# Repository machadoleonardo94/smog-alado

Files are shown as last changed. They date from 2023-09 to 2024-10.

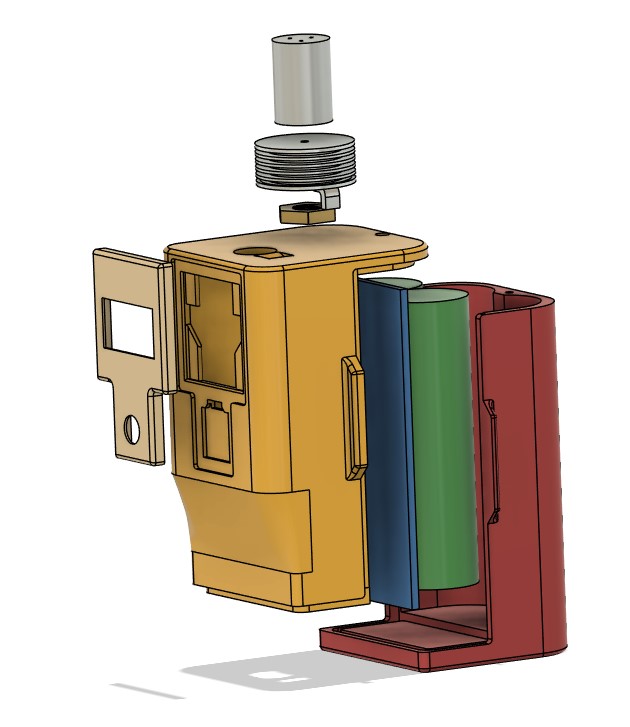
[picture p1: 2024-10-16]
3D files/Portable/Assembly.jpg

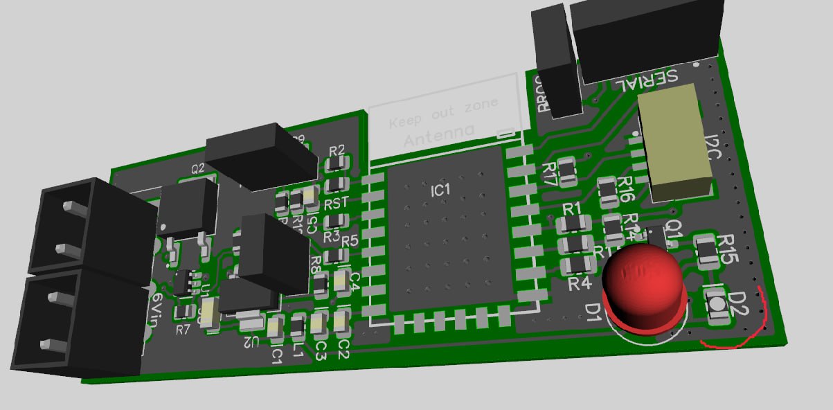
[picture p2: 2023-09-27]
board.jpg

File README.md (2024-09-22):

# smog-alado
Desktop and portable heating element controller.

## Tested uses: 
* Precise temperature control for coffee machines
* SMD soldering hotbed
* Aromatherapy diffusers

## Current hardware versions: ESP12F and ESP32-C3
* ESP12F board noes not support wakeup from deep sleep, but accepts 12V input. Aimed at desktop devices running on external power sources. It also uses the integrated ADC that requires calibration.
* ESP32-C3 board includes deepsleep, 16bit 4channel ADC (two thermistors, input voltage and current on load), USB type-C connector (charging and programming) and a WS2812B LED for debug and fancy lights.
* The 12F hardware version is considered done and more accessible, while the C3 version is a work in progress. Current C3 PCB version has wiring mistakes and should be avoided while the C3V2 is being built.
* Both versions can be wired on perfboard using NodeMCU modules and an external MOSFET or SSR if the challanger is bold.

## Mileage may vary, use at your own risk.

Portable version with 1S2P 18650 battery and 510 connector:



Portable version with 2S1P 21700, homemade heating element:



Current devkit:



## Main Features:
* PID heating to setpoint
* Single pushbutton control
* 0.96" OLED display
* OTA firmware upload
* Telnet debugging
* Auto power off

## Minimum required parts besides components BoM:
* 1x Power source
* 0.15mm NiCr wire
* Heat resistant cable  
* 1x RS232 USB to TTL module 
* 1x PCB
* 1x 100k NTC 3950 thermistor
* 1x 40N02 TO252 N-channel MOSFET or equivalent module
* 1x 12x12mm pushbutton (or whatever)
* 1x 0.96" OLED I2C display

## Recomended power sources (12F):
* 2S1P 21700 li-ion batteries with 2S BMS
* 2S lithium battery charger circuit
* 9V~12V 2A brick power supply

## Current issues (3C): 
* Missing GND connection on I2C connector;
* Button wrongly wired to 3V3. Cut the trace and connect directly to Vin;
* Gate driver does not hold MOSFET off, requires a bleeding resistor between gate and source MOSFET pins;
* 12 pin USB C connector is fucking terrible to solder correctly, so I've added an external header for serial programming and a backup 6 pin connector for charging;
* I had the dumb and forgot the antenna, so now I either solder an 1U footprint or deal with a lump on the 3D case.

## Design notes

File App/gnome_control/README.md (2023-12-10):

# gnome_control

A new Flutter project.

## Getting Started

This project is a starting point for a Flutter application.

A few resources to get you started if this is your first Flutter project:

- [Lab: Write your first Flutter app](https://docs.flutter.dev/get-started/codelab)
- [Cookbook: Useful Flutter samples](https://docs.flutter.dev/cookbook)

For help getting started with Flutter development, view the
[online documentation](https://docs.flutter.dev/), which offers tutorials,
samples, guidance on mobile development, and a full API reference.

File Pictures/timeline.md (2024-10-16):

## Project timeline 

### Gnome

October 2019. First device, running on 3D printer motherboard and firmware (Ramps 1.3 and Marlin 1.X).

### Gnome on the Cloud (IoD)



First prototype on dedicated hardware and firmware, with hookah hose outputs (up to 4).

### The Prism

Heating element fixed on high temperature silicone, replaceable with GX16-4 connector.

### Portable gnome

Running 3S batteries, able to run about 3 bowls before charging.

### First handheld device

Printed on glow in the dark filament.

### Current development version



With 2 21700 batteries, running on an ESP32-C3, focused on assembly ease.

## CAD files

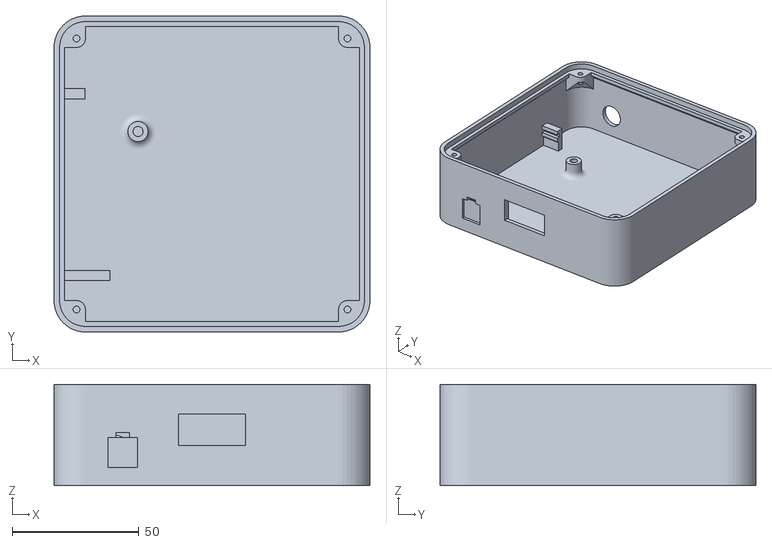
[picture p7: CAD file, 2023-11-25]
3D files/Desktop/Main body_120mm.stl
124.8 x 124.8 x 40.0

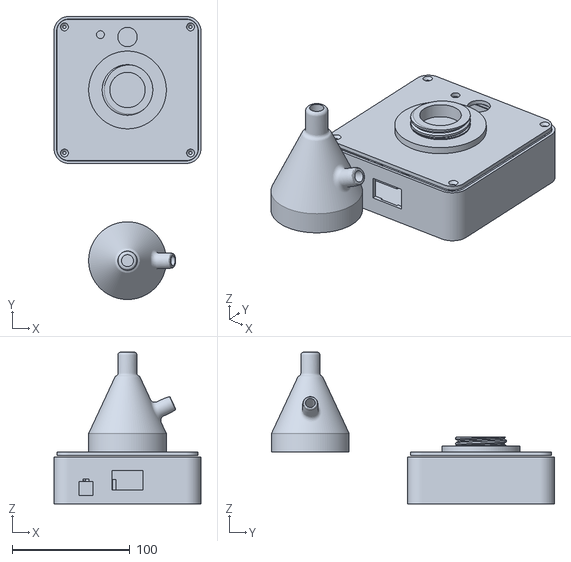
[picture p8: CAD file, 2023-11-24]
3D files/Desktop/Gnome_full.stl
124.8 x 240.4 x 129.0

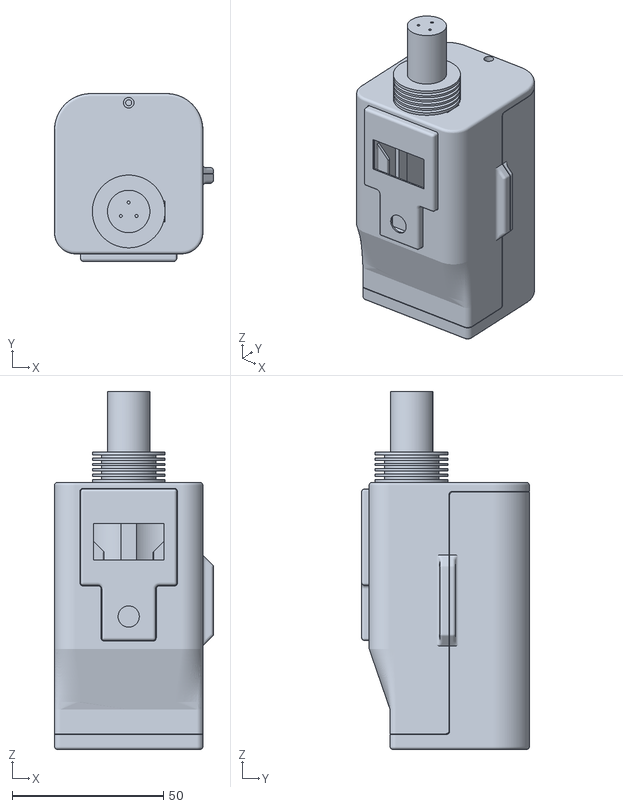
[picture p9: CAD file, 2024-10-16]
3D files/Portable/GnomeC3-V1 v23.stl
52.5 x 55.4 x 118.2

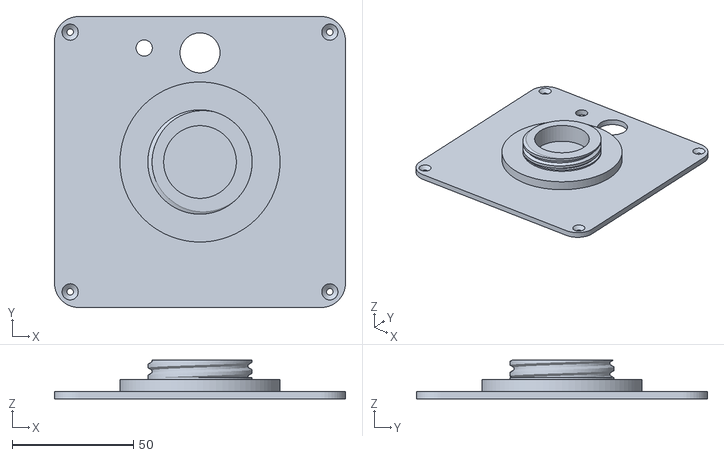
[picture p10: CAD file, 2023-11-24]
3D files/Desktop/Lid.stl
120.0 x 120.0 x 16.0

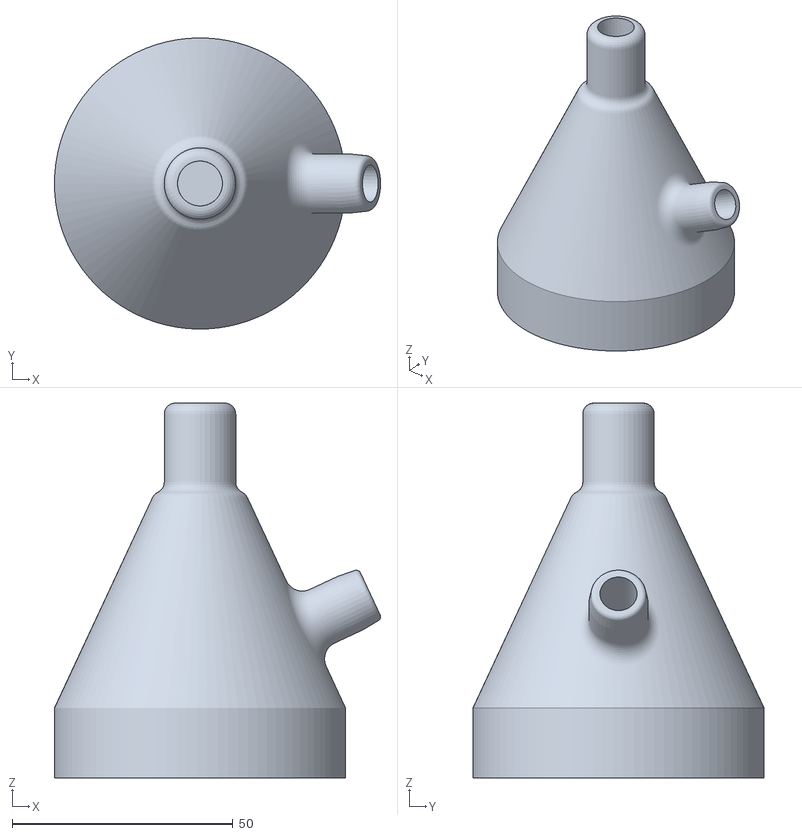
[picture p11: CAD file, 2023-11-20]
3D files/Desktop/Bowl_base_10mm.stl
73.9 x 66.0 x 85.0

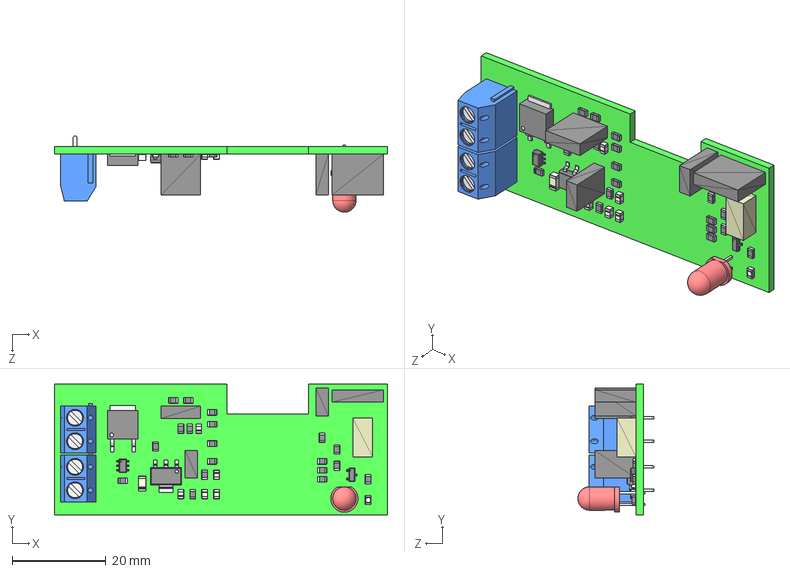
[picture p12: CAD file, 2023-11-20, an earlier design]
Board files/gnome_V3/3D_step.step
71.1 x 27.9 x 16.3 mm
Board_3D_step
DG306-5.0-02P-12-00AH x 2
CAPP_0805_M x 5
293D104X0035A2TE3
LED-5mm_Round_Red
LED_0805(2012_Metric)_M_Red
RES_0805_M x 19
2N7002,215
FDD86250-F085
FD2024S
AMS1117-3.3V
BM04B-GHS-TBT(LF)(SN)
PPTC021LFBN-RC x 2
PPTC041LFBN-RC
PPTC031LFBN-RC

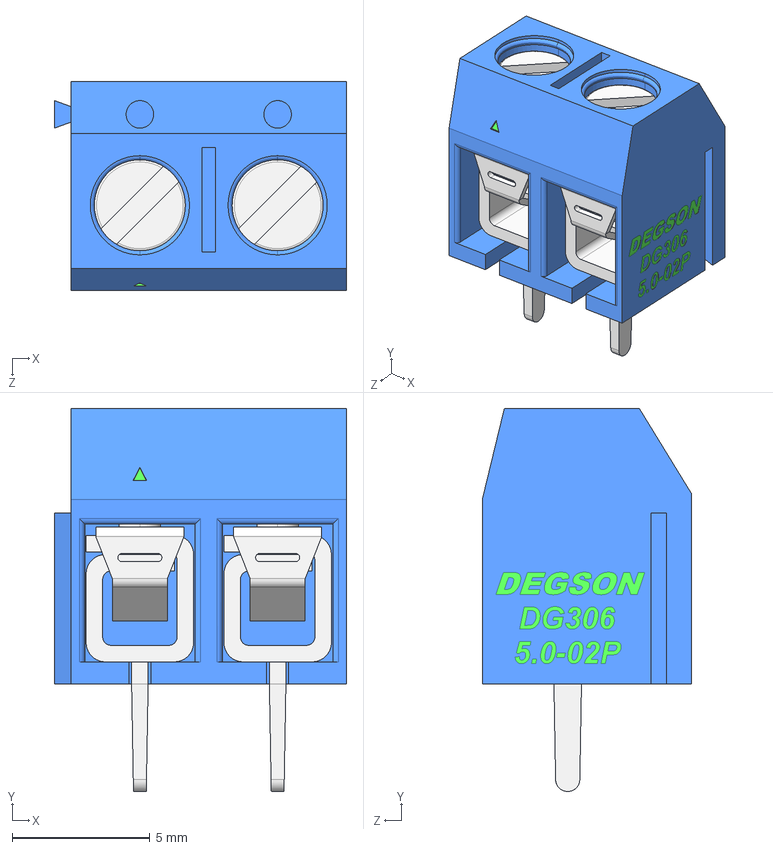
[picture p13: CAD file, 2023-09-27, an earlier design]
Board files/gnome_V3/DG306-5.0-02P-12-00AH.STEP
10.6 x 13.9 x 7.60 mm

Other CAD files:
3D files/Desktop/Main body.stl
3D files/Desktop/Glass Joiner v14.f3z
3D files/Portable/GnomeC3-V1-21700.f3d
3D files/Portable/Gnome_12FV2.f3z

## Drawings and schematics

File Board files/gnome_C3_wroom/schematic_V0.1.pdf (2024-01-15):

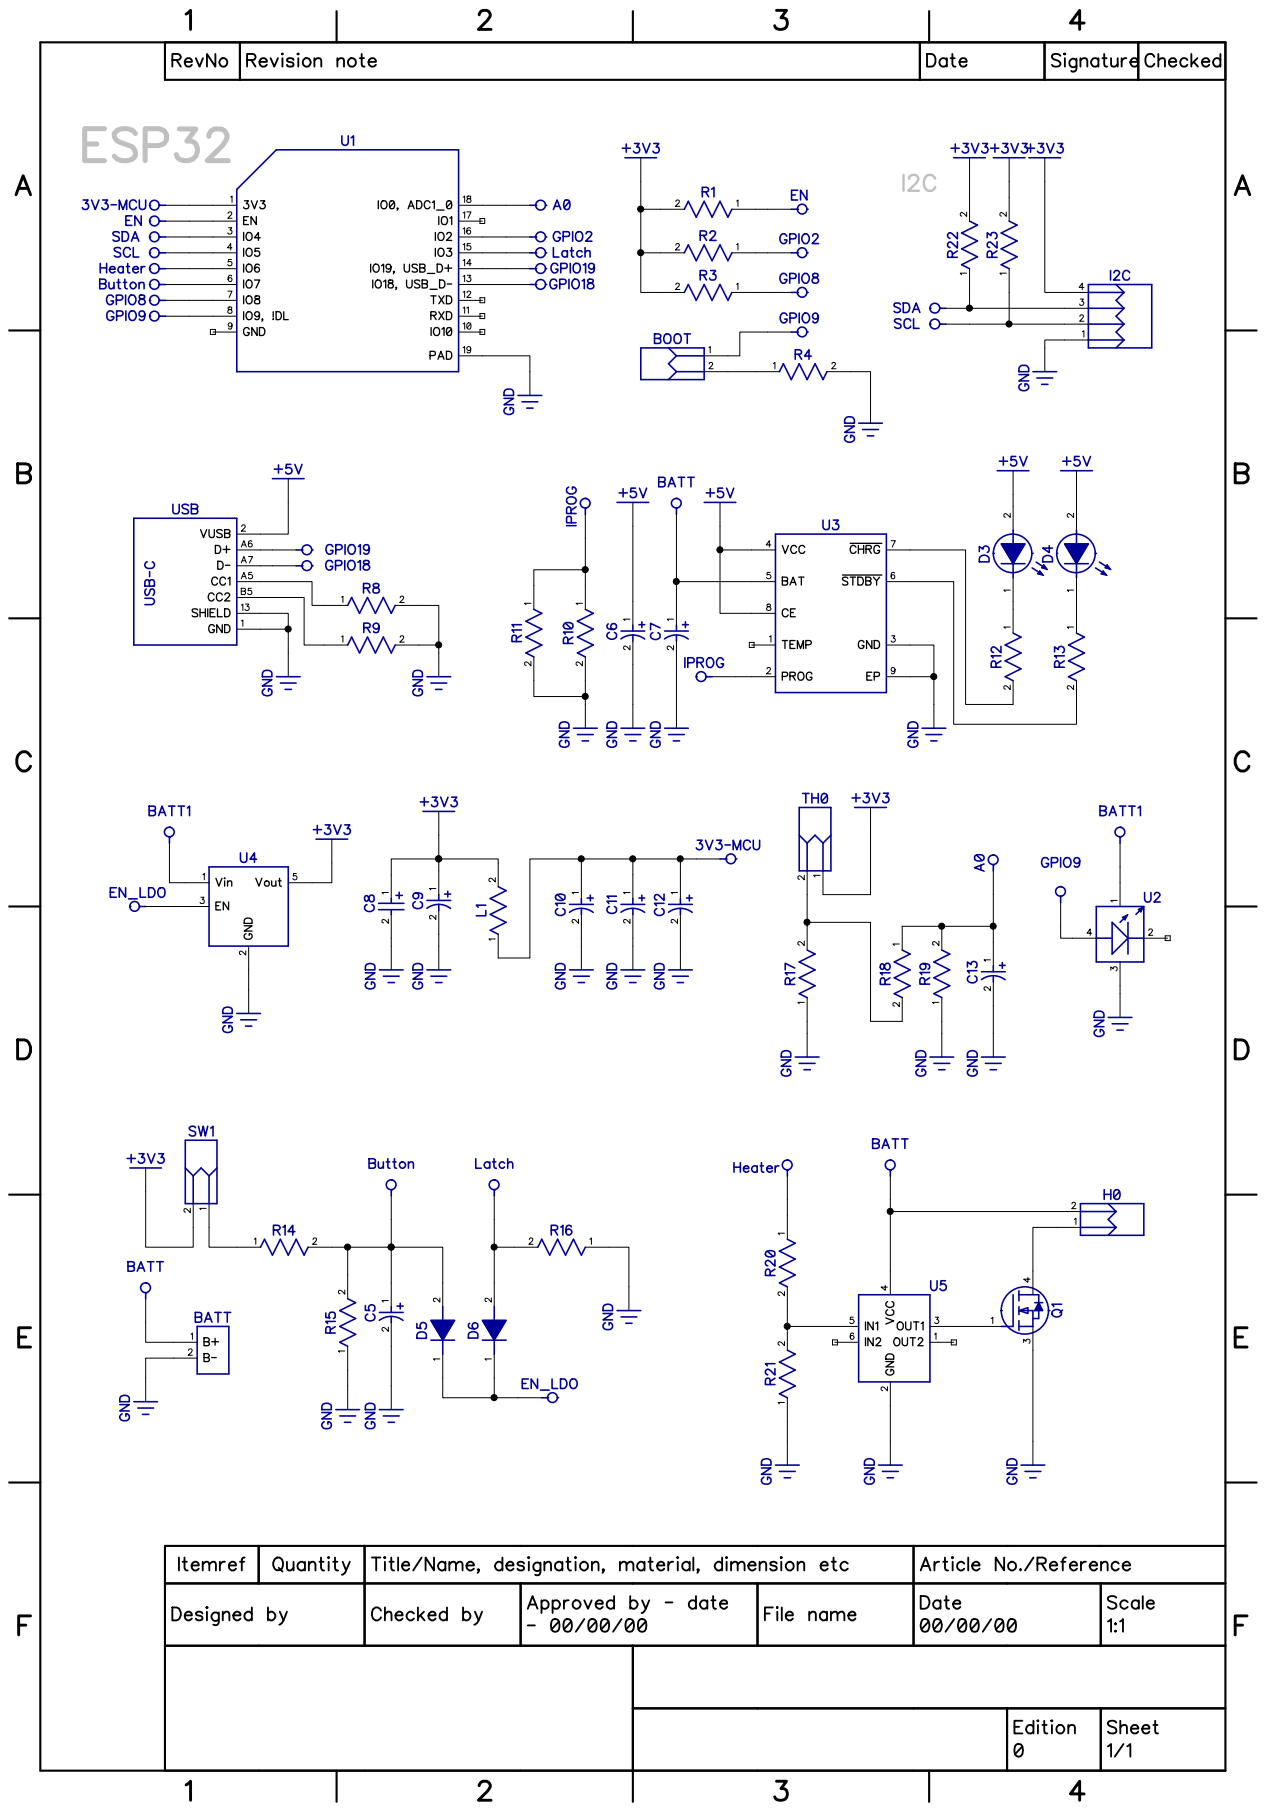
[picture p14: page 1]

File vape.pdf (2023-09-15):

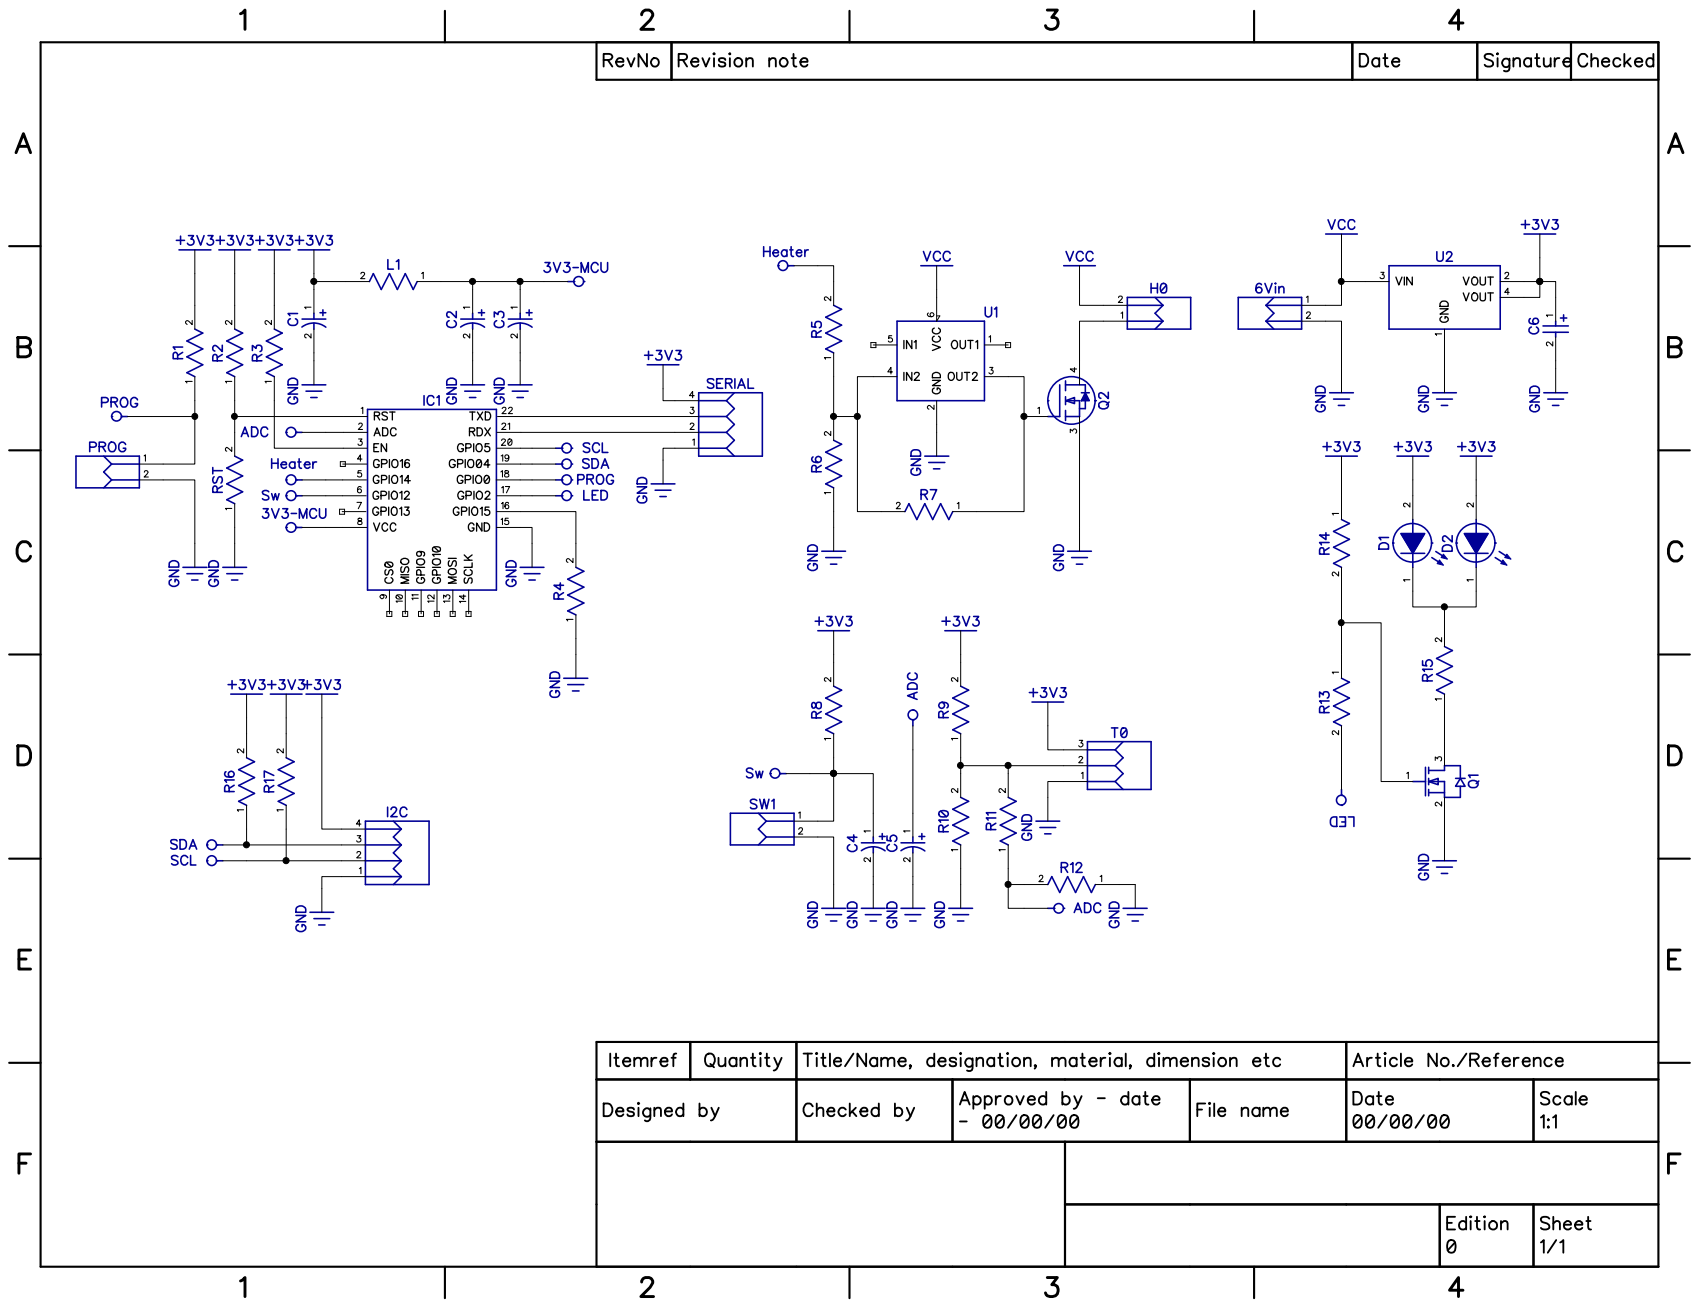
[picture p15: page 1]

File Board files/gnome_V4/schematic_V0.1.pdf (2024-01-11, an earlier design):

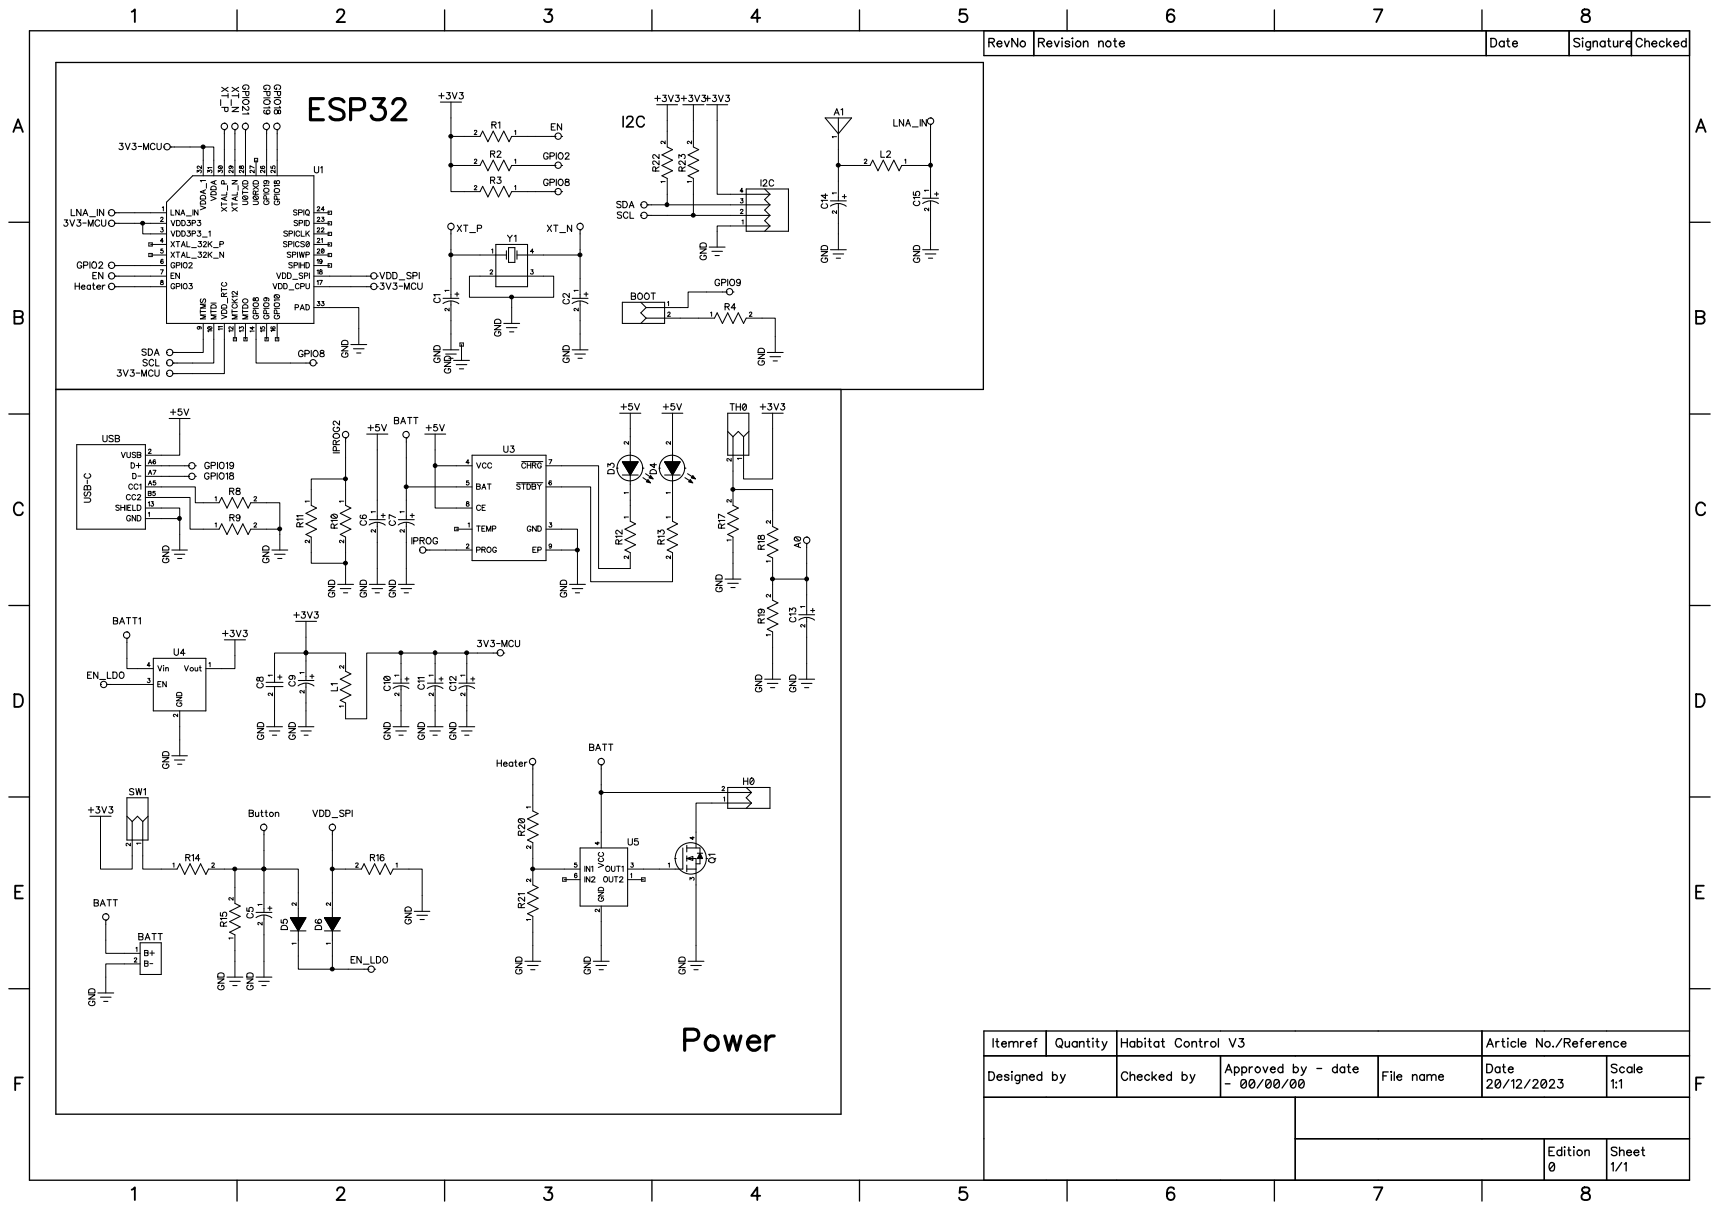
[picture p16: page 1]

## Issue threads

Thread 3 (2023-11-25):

Reconnecting issues

machadoleonardo94, 2023-11-25:
After losing connection to the wifi, the routine will create a new captive portal that does not enable configuration. A reboot will reconnect to old credentials if available, but currently there's no way to reset locally without opening the case and removing the battery.

Either enabling soft reset, or fixing reconnect routine will fix the issue.

Closed 2024-01-03.

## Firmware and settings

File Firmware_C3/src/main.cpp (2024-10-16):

//* ---------------------- IMPORTS ----------------------
//* Shared:
#include "shared/dependencies.h"

void shutdownESP();

void setup()
{
  pinMode(buttonPin, INPUT_PULLUP);
  pinMode(latchPin, OUTPUT);
  digitalWrite(latchPin, HIGH);
  pinMode(heater, OUTPUT);
  ledcAttach(heater, 1000, 10);
  digitalWrite(heater, 0);

  Serial.begin(115200);
  Serial.println("setup");
  workingDisplay = setup_display();
  setup_LEDS();

  setLED(redLED);
  long wakeupTimer = millis();
  while (((millis() - wakeupTimer) < 2000) && clickCounter < 3)
  {
    buttonPress();
    delay(50);
  }
  if (clickCounter < 2)
  {
    shutdownESP();
  }
  setLED(greenLED);
  clickCounter = 0;

  setup_ESP32();
}

void loop()
{
  ArduinoOTA.handle();

  if ((millis() - globalTimer) > SAMPLING_TIMER)
  {
    buttonPress();
    thermistor = calculate_resistance();
    heaterTemperature = steinhart(thermistor);
    controlPower(powerLevel);
    globalTimer = millis();
    idleTimer++;
    logTimer++;
    adcTimer++;
    screenTimer++;
  }

  if ((logTimer > (SAMPLES_TO_SEC / 10))) // logs variables every 100ms if awake
  {
    logTimer = 0;
    battery = analogReadMilliVolts(1) * 8.2 / 4095;
  }

  if (screenTimer > SAMPLES_TO_SEC / 10)
  {
    screenTimer = 0;
    updateDisplay();
    if (buttonState)
      sampleRandomLED();
    else
      setLED(0, 50, 0);
  }

  if (idleTimer > (SAMPLES_TO_SEC / 2))
  {
    clickCounter = 0;
    // setLED(0, 0, 0);
    // digitalWrite(latchPin, LOW);
    // esp_deep_sleep_start();
  }

  if ((clickCounter > 5) || (idleTimer > (5 * SAMPLES_TO_MIN)))
    shutdownESP();
}

void shutdownESP()
{
  setLED(0, 0, 0);
  delay(50);
  // digitalWrite(latchPin, LOW);
  esp_deep_sleep_start();
}

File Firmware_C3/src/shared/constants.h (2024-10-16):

#if !defined(PROJECT_GLOBAL_CONSTANTS)
#define PROJECT_GLOBAL_CONSTANTS

//* Multiplier to convert microseconds to seconds.
#define one_second_in_microseconds 1000000

//* Sampling timers
#define SAMPLING_TIMER 10                    // delay between counting increments
#define SAMPLES_TO_SEC 1000 / SAMPLING_TIMER // how many increments every 1s
#define SAMPLES_TO_MIN 60000 / SAMPLING_TIMER

//* Sleep timer
#define TIME_TO_SLEEP minutes * 60 * SAMPLES_TO_SEC - 1

//* Time zone for NTP time sync
#define TIME_ZONE TZ_America_Sao_Paulo

//* Temperature limit to avoid burnout
#define tempMax 205

//* Pulldown resistor R10
#define PULLDOWN_RES 4700

//* Higher resolution for PWM output (default 256)
#define ANALOG_RANGE 1024

//* EEPROM addresses for wifi
#define EEPROM_WIFI_SSID_START 128
#define EEPROM_WIFI_PASS_START 192

//* EEPROM addresses for PID
#define EEPROM_KP_ADDRESS 0
#define EEPROM_KI_ADDRESS 32
#define EEPROM_KD_ADDRESS 64

#endif // PROJECT_GLOBAL_CONSTANTS

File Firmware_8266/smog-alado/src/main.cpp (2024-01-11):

//* ---------------------- IMPORTS ----------------------
//* Shared:
#include "shared/dependencies.h"
//* Utilities:
#include "utilities/OTA.h"
#include "utilities/WIFI.h"
#include "utilities/logger.h"
#include "utilities/nuke_eeprom.h"
#include "utilities/lightsleep.h"
#include "utilities/telnet.h"
#include "utilities/PID.h"
#include "utilities/webserver.h"
//* Components:
#include "components/ADS1115/setup.h"
#include "components/THERMISTOR/setup.h"
#include "components/HEATER/setup.h"
#include "components/PUSHBUTTON/setup.h"
#include "components/DISPLAY/setup.h"

void setup()
{
  BLINKY
  delay(1000);
  Serial.begin(115200);
  Serial.println("setup");
  pinMode(ledPin, OUTPUT);
  pinMode(buttonPin, INPUT_PULLUP);
  pinMode(heater, OUTPUT);
  pinMode(A0, INPUT);
  digitalWrite(ledPin, LOW); // builtin LED set to ON on boot
  digitalWrite(heater, LOW); // heater set to OFF on boot
  WiFi.mode(WIFI_OFF);

  workingDisplay = setup_display();
  workingADS = setup_ADS1115();
  analogWriteRange(ANALOG_RANGE);
  LittleFS.begin();
  // LittleFS.format();
  setup_WIFI();
  setup_OTA();
  setupPID();
  setupWebServer();

  workingADS = setup_ADS1115();
  timeZoneSet = setup_TELNET();
  // TODO: implement a routine to periodicaly check if timezone is set, otherwise telnet won't work
  analogWriteRange(ANALOG_RANGE);

  myPID.SetOutputLimits(0, ANALOG_RANGE);
  myPID.SetMode(AUTOMATIC);
  // changeAutoTune();  // Initiate auto-tuning at startup

  os_update_cpu_frequency(10);
}

void loop()
{
  ArduinoOTA.handle();

  myPID.Compute();

  buttonPress(buttonPin);

  if (adcTimer > (SAMPLES_TO_SEC / 5)) // reads ADC every 200ms
  {
    adcTimer = 0;
    thermistor = calculate_resistance();
    heaterTemperature = steinhart(thermistor);
    runHeater(preset);
  }

  if (!sleepy && (logTimer > SAMPLES_TO_SEC)) // logs variables every 1s if awake
  {
    logTimer = 0;
    digitalWrite(ledPin, !digitalRead(ledPin));
    run_logger();
    TelnetPrint();
    if (workingDisplay)
      updateDisplay();
  }

  if (idleTimer > (TIME_TO_SLEEP)) // sleep after 10 minutes
  {
    sleepRoutine();
  }

  if ((millis() - globalTimer) > SAMPLING_TIMER)
  {
    globalTimer = millis();
    idleTimer++;
    logTimer++;
    adcTimer++;
  }
}

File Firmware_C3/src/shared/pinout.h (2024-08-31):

//? ------------------------------------------------------------------------------------------
//*! This file contains all the hardware pinout definitions for the project.
//? ------------------------------------------------------------------------------------------

#ifndef PROJECT_GLOBAL_PINOUT
#define PROJECT_GLOBAL_PINOUT

//* ---------------------- ESP32 Project Pinout ----------------------
//* ANALOG OUT:
#define heater 6
//* ANALOG IN:
#define analogIn0 A0
//* DIGITAL OUT:
#define LED_output 10
#define latchPin 3
//* DIGITAL IN:
#define buttonPin 7
//* I2C PINS:
#define SDA 4
#define SCL 5

//* ---------------------- ADS1115 Channels Used ----------------------
#define thermistor_channel 0

#endif // PROJECT_GLOBAL_PINOUT

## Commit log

2023-09-06 Schematic review
2023-09-16 Minor silkscreen fixes
2023-09-16 V0.0.1
    First PCB files
2023-09-27 Create board.jpg
    3D render with test footprints
2023-09-27 Minor cosmetic upgrade
    Added step files for power header
    [3D_step.step, DG306-5.0-02P-12-00AH.STEP]
2023-10-13 First usable firmware upload
    * Declares inputs and outputs;
    * Calculates temperature from thermistor installed on A0 with 1k pulldown resistor;
    * Reads button presses to define preset heating temperatures
2023-10-16 Added oversampling to ADC
    Script now does 16 readings, then divides the sum by 16 to sample average.
2023-10-24 added proportional heating
2023-11-20 3D files update
    Added main body, lid and a 10mm downstem coupler to 13.4mm silicone hose
    [3D_step.step, Bowl_base_10mm.stl, Glass Joiner v14.f3z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]
2023-11-22 added OTA bare minimum
    [Lid.stl, Main body.stl]
2023-11-22 draft for ESP32
2023-11-22 Major rework on code organization
    [constants.h]
2023-11-22 Added clicky button, rework on timers
    [clicky.h, constants.h, main.cpp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]
2023-11-23 Implemented failsafe in case of missing ADS
    [main.cpp, variables.h]
2023-11-23 STL files for 3D printing
    [Bowl_base.stl, Gnome_full.stl, Lid.stl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]
2023-11-23 Heater treats preset temp inside its function
2023-11-23 Added failsafe for thermistor (still dumb if open)
    [read_temp_thermistor.h]
2023-11-23 Major rework on function calling
    [main.cpp]
2023-11-24 Added values for 10K NTC thermistor
2023-11-24 New 3D files
    [Lid_120mm.stl, Main body_120mm.stl]
2023-11-25 ESP will softreset after 5s button press
2023-11-25 Only writes on display if device HAS a display
2023-11-25 Guess what, reset and restard do different things
    [clicky.h]
2023-11-25 Added wifi menu screen and sleep timer
2023-12-03 preset is treated inside button click
2023-12-05 Heater no longer overflows with stupid PID values
    [constants.h, variables.h]
2023-12-06 PID control + PID autotune
    Change heater control logic to full PID activation, plus implementation of PID autotune activated by long press of button.
    Also, correction and cleanup of logger and telnet.
    [clicky.h, constants.h, main.cpp]
2023-12-06 PID is now always updated
2023-12-06 hotfix to undo damages done during merge
    [main.cpp, variables.h]
2023-12-06 Correction to PID autotune calling
    [clicky.h]
2023-12-06 ESPAsync + WebServer
    WiFi tools changed to ESPAsync toolkit, plus implementation of webserver to display data and control PID parameters on-the-go
2023-12-07 PID from EEPROM, webserver
    Save values for PID to EEPROM from
    the webserver. Read these values at boot.
    Added buttons to set new sleep time and reboot esp.
    [constants.h, main.cpp, variables.h]
2023-12-12 Refactoring PID
2023-12-20 quick stage
2023-12-27 ESP32-C3 work in progress
2023-12-28 Footprints review
2023-12-29 Moved files
    To do: add libs
    [3D_step.step, DG306-5.0-02P-12-00AH.STEP]
2023-12-30 Features update
    Added antenna and matching circuit
    Removed mini battery
    Removed mini battery charging circuit
2023-12-30 Now reads temperature from A0 if ADS is missing
    [main.cpp, read_temp_thermistor.h]
2024-01-09 3D files for portable unit
    [Bowl_base.stl, Bowl_base_10mm.stl, Glass Joiner v14.f3z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]
2024-01-11 Added tabletop holder for portable version
    [Gnome holder.stl]
2024-01-11 Now uses fancy heating control
2024-01-11 hotfix on heater
2024-01-11 Revert "PIDs"
    This reverts commit 3956cc598d35d5bd09890c9e7c50b7c76d7adc9d.
    [constants.h, main.cpp, variables.h]
2024-04-30 Renaming of main board files
2024-09-02 Added pretty LED
2024-09-03 Inits LED before wifi for faster boot diag
2024-09-03 Display GND was missing connection to ground plane
2024-09-04 Added thermistor and battery readings
2024-09-04 Holding button now puts ESP to sleep
2024-09-11 Addedd heating routine
2024-09-11 Updated buttonPress routine
2024-09-11 Updated screen for runtime and PWM output
2024-09-11 Added 3D files for C3 casing
    [GnomeC3-V1-21700.f3d, GnomeC3-V1-21700.stl]
2024-09-13 Rotate display to ease wiring
2024-09-19 added C3V2 schematic
2024-09-20 Added C3-V2 schematic and layout
2024-09-20 Added power level submenu
2024-09-21 Added total heating time to display
2024-09-21 Current PCB development
2024-09-23 Reduced minimum power output
2024-09-27 Heating calculations moved to heater routine
2024-09-28 Added boot misclick prevention
    [main.cpp]
2024-10-01 Added board files for revision
2024-10-04 Added constant heating mode
2024-10-06 Updated 3D files for portable version
    [GnomeC3-V1 v23.stl, GnomeC3-V1-21700.f3d]
2024-10-06 Removed old files
    [Gnome Main body.stl, Gnome body lid.stl, Gnome holder.stl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]
